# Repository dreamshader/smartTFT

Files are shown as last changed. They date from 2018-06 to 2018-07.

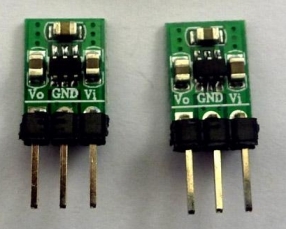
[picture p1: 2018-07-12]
doc/img/2p-mini-2-in-1-dc-dc-step-down-step-up-converter.jpg

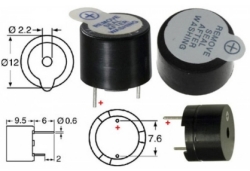
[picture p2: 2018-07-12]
doc/img/piezo-buzzer-specs-700x700_0.jpg

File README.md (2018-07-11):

---

---

<h1 id="smarttft">smartTFT</h1>
<h2 id="brief-description">Brief description</h2>
<p>There is a lot of small and cheap color TFT displays around and with this project I want to give some of them the possibility to remotely control its content. Control is done by most common function calls of the Arduino GFX Library that are transferred to a µController that executes them.</p>
<h2 id="first-prototype">First Prototype</h2>
<p>First prototype is a 1.8" TFT with a ST7735 controller and additional SD-card slot.<br>
As a µController an Arduino Pro Mini is used.<br>
Communication is done using the UART of the Arduino.<br>
A self-made case will hold the components.<br>
A buzzer is used to realize an alarm-function, a LDR makes ist possible to change brightness of the display depending on ambient light.</p>
<p><em><strong>Be aware … this is a work-in-progress project. Some parts may not or not proper work. Use at your own risc!</strong></em></p>
<h2 id="parts-list-1st-prototype">Parts List 1st Prototype</h2>
<ul>
<li>1 x Arduino Pro Mini 1 x 1.8" TFT with SD-slot</li>
<li>2 x Levelshifter with 4 channels</li>
<li>1 x Stepup/Stepdown Regulator 5 &lt;-&gt; 3V3</li>
<li>1 x LDR</li>
<li>1 x Buzzer</li>
<li>1 x Resistor 10 kOhm</li>
<li>2 x Resistor 4.7 kOhm</li>
<li>1 x Resistor 100 Ohm</li>
<li>2 x Ceramic Capacitor 100 nF</li>
<li>1 x Proto-PCB 16 rows/32 columns (around 42 x 83 mm)</li>
<li>1 x Proto-PCB 16 rows/6 columns (around 42 x 15 mm)</li>
<li>1 x Stereo Jack female 3.5 mm</li>
<li>1 x DC Jack female 3.5 mm x 1.1 mm</li>
<li>1 x 4x1 Pin Header</li>
<li>a bunch of colored wires 0.14 mm</li>
</ul>
<h2 id="wiring-via-levelshifter">Wiring via Levelshifter</h2>

<table>
<thead>
<tr>
<th>Arduino</th>
<th>Levelshifter</th>
<th>Levelshifter</th>
<th>1.8" TFT</th>
</tr>
</thead>
<tbody>
<tr>
<td>Pin #10</td>
<td>HV*</td>
<td>LV**</td>
<td>TFT_CS</td>
</tr>
<tr>
<td>Pin #9</td>
<td>HV</td>
<td>LV</td>
<td>TFT_RST</td>
</tr>
<tr>
<td>Pin #8</td>
<td>HV</td>
<td>LV</td>
<td>TFT_DC</td>
</tr>
<tr>
<td>Pin #13</td>
<td>HV</td>
<td>LV</td>
<td>TFT_SCL</td>
</tr>
<tr>
<td>Pin #11</td>
<td>HV</td>
<td>LV</td>
<td>TFT_SDA</td>
</tr>
<tr>
<td>Pin #7</td>
<td>HV</td>
<td>LV</td>
<td>SD_CS</td>
</tr>
<tr>
<td>Pin #12</td>
<td>HV</td>
<td>LV</td>
<td>SD_MISO</td>
</tr>
<tr>
<td>Pin #11</td>
<td>HV</td>
<td>LV</td>
<td>SD_MOSI</td>
</tr>
<tr>
<td>Pin #13</td>
<td>HV</td>
<td>LV</td>
<td>SD_SCL</td>
</tr>
</tbody>
</table><p>*HV means High Voltage Side<br>
**LV means Low Voltage Side</p>
<hr>
<p>Because Vcc of the TFT is 5V <strong>be aware</strong> that <strong>Jumper J1</strong> on the back side of TFT is <strong>open!</strong> Otherwise the display is damaged.</p>
<h2 id="direct-wiring">Direct Wiring</h2>

<table>
<thead>
<tr>
<th>Arduino</th>
<th>Target 1</th>
<th>Target 2</th>
<th>is for</th>
</tr>
</thead>
<tbody>
<tr>
<td>Pin #5</td>
<td>100 Ohm</td>
<td>buzzer</td>
<td>limit current</td>
</tr>
<tr>
<td>Pin #6</td>
<td>TFT LED+</td>
<td>–</td>
<td>dim backlight</td>
</tr>
<tr>
<td>Pin A0</td>
<td>LDR</td>
<td>–</td>
<td>light sense</td>
</tr>
<tr>
<td>Pin A0</td>
<td>10 kOhm</td>
<td>GND</td>
<td>pulldown</td>
</tr>
</tbody>
</table><h2 id="realized-gfx-functions">Realized GFX-functions</h2>
<ul>
<li>drawLine()</li>
<li>drawFastHLine()</li>
<li>drawFastVLine()</li>
<li>drawRect()</li>
<li>fillRect()</li>
<li>drawCircle()</li>
<li>fillCircle()</li>
<li>drawTriangle()</li>
<li>fillTriangle()</li>
<li>drawRoundRect()</li>
<li>fillRoundRect()</li>
<li>setRotation()</li>
<li>setTextWrap()</li>
<li>fillScreen()</li>
<li>setTextColor()</li>
<li>fillScreen()</li>
<li>invertDisplay()</li>
<li>drawCircleHelper()</li>
<li>fillCircleHelper()</li>
<li>drawBitmap()</li>
<li>drawChar()</li>
<li>setCursor()</li>
<li>setTextSize()</li>
<li>height()</li>
<li>width()</li>
<li>write()</li>
<li>drawPixel()</li>
<li>print()</li>
<li>println()</li>
</ul>
<p>and. last but not least,</p>
<ul>
<li>setbrightness()</li>
</ul>
<p>for dimming backlight of the TFT Display.</p>

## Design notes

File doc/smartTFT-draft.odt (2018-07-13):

smartTFT

Control TFT and TFT Touch Displays remotely

# Brief description

There is a lot of small and cheap color TFT displays around and with this project I want to give some of them the possibility to remotely control its content. Control is done by most common function calls of the Arduino GFX Library that are transferred to a µController that executes them.

µControllers that may be used are several typed of Arduino (e.g. Pro Mini) and the ESP8266 Series as well as the ESP32xx Series SoCs.

The displays that are suitable to use are the several 0.96“, 1.2“, 1.8“, 2.2“ … TFT displays and TFT displays with touch interface.

For more information about µControllers and displays see appendix A.

# Proof of concept and 1st prototype

First prototype and proof of concept is done with a ST7735 based 1.8" TFT with an additional SD-card slot.

As a µController an Arduino Pro Mini is used.

Communication is done using the UART of the Arduino.

A self-made case will hold the components.

A buzzer is used to realize an alarm-function, a LDR makes ist possible to change backlight brightness of the display depending on ambient light.

## Prototype Electronic Components

### Arduino Pro Mini

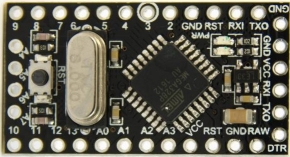
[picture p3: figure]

There are several different models of the Arduino Pro Mini available. There is no need for choosing a specific model but it is recommended not to use a 3V3 type.

### 1.8“ TFT Display

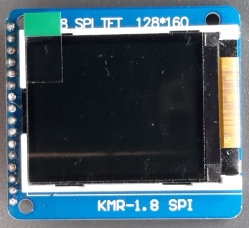
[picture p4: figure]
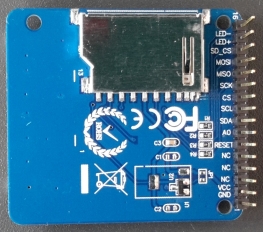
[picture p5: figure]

This documentation requires the use of a 16 pin 1.8“ TFT with card slot, based on a ST7735 controller. Keep in mind not to close jumper J1 to avoid damage of the display.

### 4 channel logic level shifter

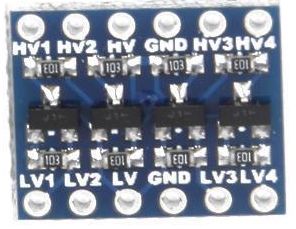
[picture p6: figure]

There is no special to annotate to this items. You may use a 8 channel level shifter instead of two pieces with 4 channels, but then you have to change the wiring to match this new condition.

### Stepup/Stepdown regulator


These are special items that will work with an input voltage from 1.8V up to 5V and will deliver a max. current of 100 mA @3.3V.

3.3V are necessary for the logical signals even if the display is powered by 5V.

### Light Dependend Resistor (LDR)

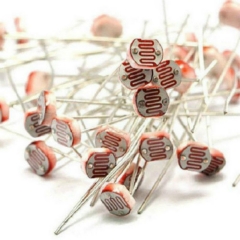
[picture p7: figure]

These cheap items will match our needs. You may get a bunch of them for only some cent. There is no reason to use other ones.

### Piezo Buzzer


This item is a standard component, too. You may use any type of buzzer working at 5V but hold in mind that the case construction only supports one with these technical data (e.g. diameter, height, ...).

### Resistors

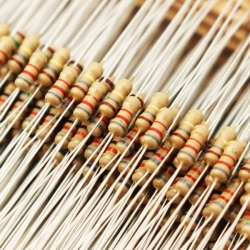
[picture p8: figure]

We need simple carbon resistors with ¼ W, one with 100 Ohm, two with 4.7 kOhm and one with 10 kOhm. See Prototype Parts List below.

### Ceramic Capacitors

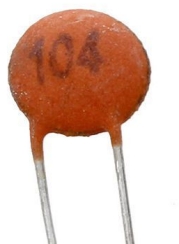
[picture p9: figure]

We need two pieces as decoupling capacitor, one for the TFT and one for the Arduino. For details have a look to the “Prototype Parts List”.

### Stereo Jack 3.5 mm

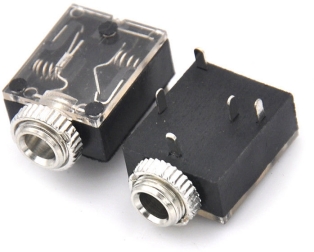
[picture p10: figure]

This is used to connect the UART pins. See sections “Preparing the Prototype PCBs” and “Wiring the Prototype” for more details.

### DC Jack

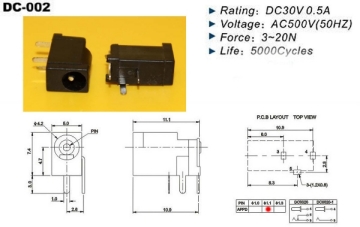
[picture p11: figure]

Connector for power supply (5V). See sections “Preparing the Prototype PCBs” and “Wiring the Prototype” for more details.

### Pin Header 90 degree

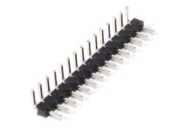
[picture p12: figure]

This header is used to connect the smartTFT to an I2C-Bus. Only three pins are used for SDA, SCL and GND. See sections “Preparing the Prototype PCBs” and “Wiring the Prototype” for more details.

### Prototype PCB

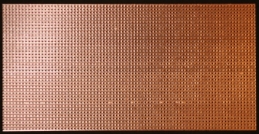
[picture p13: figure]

We need two small pieces of it. See section “Preparing the Prototype PCBs” for dimensions.

### Crimp Headers

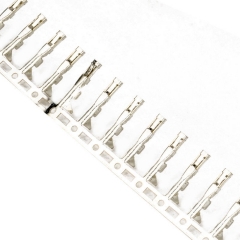
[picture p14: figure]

For the Prototype we’ll wire some connections with these for easily change them.

### Some Colored Wires

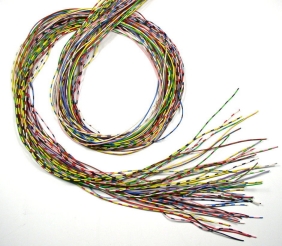
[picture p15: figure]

To make life easier onnections are made by colored wires.

### Prototype Parts List

- 1 x Arduino Pro Mini
- 1 x 1.8" TFT with SD-slot
- 2 x Levelshifter with 4 channels
- 1 x Stepup/Stepdown Regulator 5 <-> 3V3
- 1 x LDR
- 1 x Buzzer
- 1 x Resistor 10 kOhm
- 2 x Resistor 4.7 kOhm
- 1 x Resistor 100 Ohm
- 2 x Ceramic Capacitor 100 nF
- 1 x Stereo Jack female 3.5 mm
- 1 x DC Jack female 3.5 mm x 1.1 mm
- 1 x 4x1 Pin Header 90 degree
- 1 x Proto-PCB 16 rows/32 columns (around 42 x 83 mm)
- 1 x Proto-PCB 16 rows/6 columns (around 42 x 15 mm)
- some crimp headers
- a bunch of colored wires 0.14 mm

## Preparing the Prototype PCBs

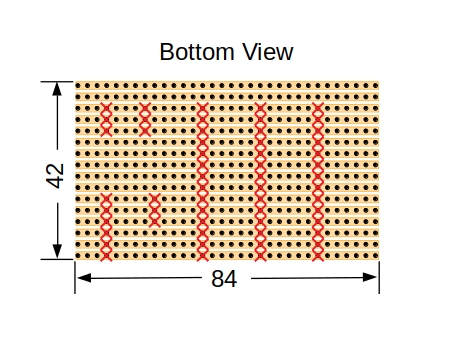
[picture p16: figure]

Cut off a piece from the strip board matching above size. Cut all connections where a red cross appears in the above drawing using a drill or a cutter knife. This will be used as the mainboard.

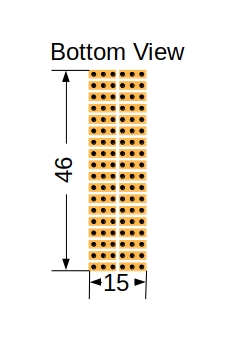
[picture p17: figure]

Cut a smaller piece from the strip board with sizes mentioned above for the connector board.

## Wiring the Prototype

### Textual Description

Arduino | Via | To | Target
Pin #10 | HV* | LV** | TFT_CS
Pin #9 | HV | LV | TFT_RST
Pin #8 | HV | LV | TFT_DC
Pin #13 | HV | LV | TFT_SCL
Pin #11 | HV | LV | TFT_SDA
Pin #7 | HV | LV | SD_CS
Pin #12 | HV | LV | SD_MISO
Pin #11 | HV | LV | SD_MOSI
Pin #13 | HV | LV | SD_SCL
Pin #5 | 100 Ohm | Buzzer +
Pin #6 | -- | TFT LED+
Pin A0 | -- | LDR
Pin A0 | 10 kOhm | GND

*HV means Levelshifter High Voltage Side

**LV means Levelshifter Low Voltage Side

### Visualization of wiring

### Schematic

## Complete the Prototype

## Software on Arduino

## Linux Testprogram

## Conclusion

Realized GFX-functions

- drawLine()

- drawFastHLine()

- drawFastVLine()

- drawRect()

- fillRect()

- drawCircle()

- fillCircle()

- drawTriangle()

- fillTriangle()

- drawRoundRect()

- fillRoundRect()

- setRotation()

- setTextWrap()

- fillScreen()

- setTextColor()

- fillScreen()

- invertDisplay()

- drawCircleHelper()

- fillCircleHelper()

- drawBitmap()

- drawChar()

- setCursor()

- setTextSize()

- height()

- width()

- write()

- drawPixel()

- print()

- println()

and. last but not least,

- setbrightness()

for dimming backlight of the TFT Display.

smartTFT draft

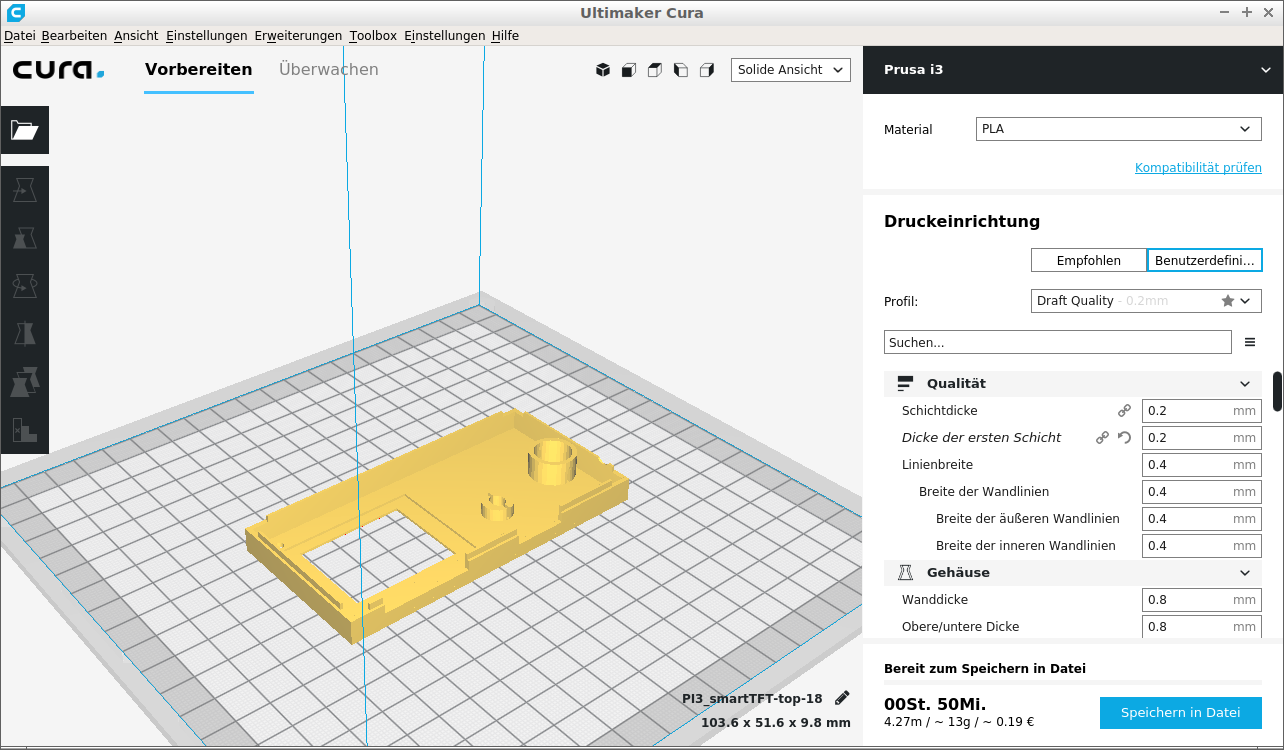
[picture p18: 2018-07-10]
doc/img/smartTFT-cura-top.png

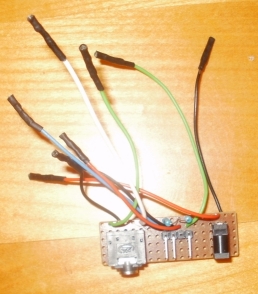
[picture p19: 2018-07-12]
doc/img/smartTFT-connector-small.jpg

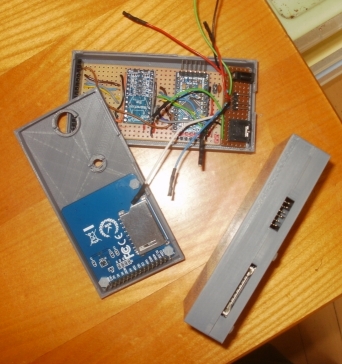
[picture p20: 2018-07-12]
doc/img/smartTFT-proto1-small.jpg

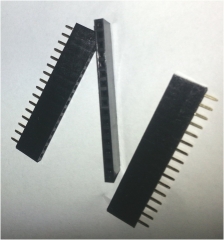
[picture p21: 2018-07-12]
doc/img/pinheader-female.jpg

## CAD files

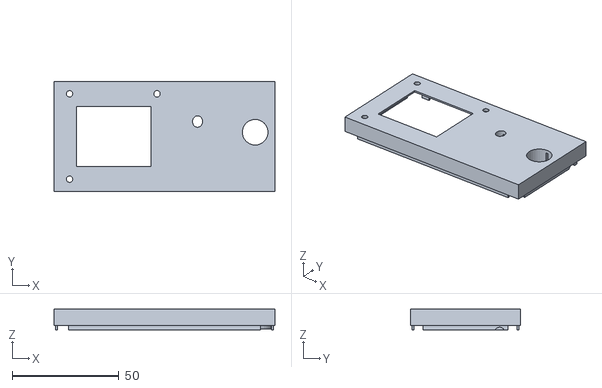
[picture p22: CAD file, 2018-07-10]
blender/exports/smartTFT-top-18.stl
103.6 x 51.6 x 9.80

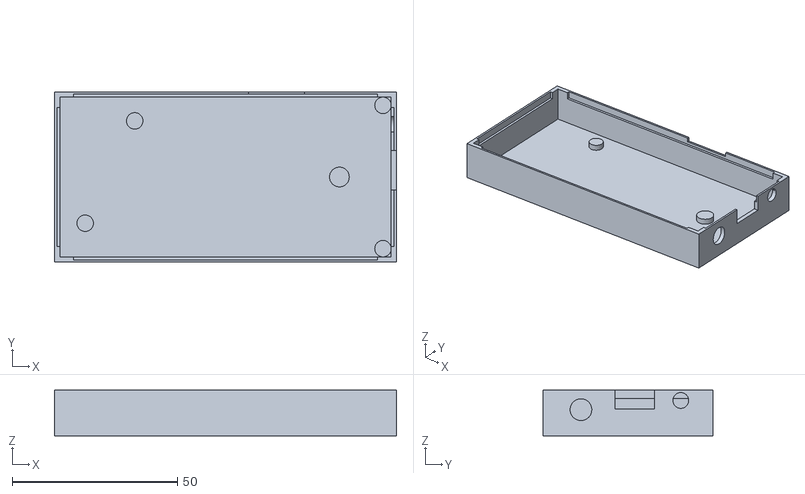
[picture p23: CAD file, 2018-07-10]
blender/exports/smartTFT-bottom-18.stl
103.6 x 51.6 x 13.8

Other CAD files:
blender/ldr.blend
blender/smartTFT-bottom-18.blend
blender/smartTFT-parts-bottom-18.blend
blender/smartTFT-parts-top-18.blend
blender/smartTFT-top-18.blend

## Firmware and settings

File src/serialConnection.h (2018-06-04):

/*
 ***********************************************************************
 *
 *  serialConnection.h - a class for simplifying access to a
 *                       serial line
 *
 *  Copyright (C) 2018 Dreamshader (aka Dirk Schanz)
 *
 *  Licensed under the Apache License, Version 2.0 (the "License");
 *  you may not use this file except in compliance with the License.
 *  You may obtain a copy of the License at
 *  
 *      http://www.apache.org/licenses/LICENSE-2.0
 *  
 *  Unless required by applicable law or agreed to in writing, software
 *  distributed under the License is distributed on an "AS IS" BASIS,
 *  WITHOUT WARRANTIES OR CONDITIONS OF ANY KIND, either express or implied.
 *  See the License for the specific language governing permissions and
 *  limitations under the License.
 *
 ***********************************************************************
 */

#ifndef _SERIAL_CONNECTION_H_
#define _SERIAL_CONNECTION_H_

#include <iostream>
#include <string>
#include <sys/types.h>
#include <stdio.h>
#include <stdlib.h>
#include <unistd.h>
#include <string.h>
#include <stdbool.h>
#include <sys/param.h>
#include <fcntl.h>
#include <termios.h>


#ifdef __cplusplus
extern "C" {
#endif
 
using namespace std;

#define DEFAULT_CONNECTIONTYPE -1
#define DEFAULT_DEVICE           "/dev/ttyUSB0"
#define DEFAULT_BAUD             38400
#define DEFAULT_DATABIT          8
#define DEFAULT_STOPBITS         1
#define DEFAULT_PARITY           'N'
#define DEFAULT_HANDSHAKE        'N'

#define E_OK                       0
#define E_FAIL                    -1

#define E_PARAM_BAUDRATE         -10
#define E_PARAM_DATABIT	         -11
#define E_PARAM_PARITY	         -12
#define E_PARAM_STOPBITS         -13
#define E_PARAM_HANDSHAKE        -14
#define E_PARAM_DEVICE           -15
#define E_PARAM_NULL             -16
#define E_PARAM_NOFD             -17
#define E_PARAM_LENGTH           -18
#define E_NULL_CONNECTION        -19

#define CONNECTION_TYPE_UART      'u'
#define CONNECTION_TYPE_I2C       'i'
#define CONNECTION_TYPE_SPI       's'

#define CONNTYPE_SET            1

#define INATERFACE_SET          2
#define SPEED_SET               4
#define PARITY_SET              8
#define DATABITS_SET           16
#define STOPBITS_SET           32
#define UART_PARAM_COMPLETE    63

#define I2CSDA_SET              2
#define I2CSCL_SET              4
#define I2CADDR_SET             8
#define I2C_PARAM_COMPLETE     15

#define SPIMOSI_SET             2
#define SPIMISO_SET             4
#define SPISCLK_SET             8
#define SPICS_SET              16
#define SPI_PARAM_COMPLETE     31



// #define SEND_BUFFER_SIZE    1024

class serialConnection {

    private:
        int16_t        dev_fd;
        struct termios newtio;
        bool           dataReceived;
        int8_t         connType;
        uint32_t       connFlags;

        char           *device;
        uint32_t       baud;
        int16_t        databits;
        int8_t         parity;
        int16_t        stopbits;
        int8_t         handshake;

//     uint8_t _sendBuffer[SEND_BUFFER_SIZE];

    public:
        int            errorNum;

        serialConnection( char *devname = (char*) DEFAULT_DEVICE, 
                          uint32_t baud = DEFAULT_BAUD, 
                          int16_t databits = DEFAULT_DATABIT, 
                          int8_t parity = DEFAULT_PARITY, 
                          int16_t stopbits = DEFAULT_STOPBITS, 
                          int8_t handshake = DEFAULT_HANDSHAKE )
        {

            if( isValidDevice( devname ) )
            {
                this->device = strdup(devname);
                if( isValidBaud( baud ) )
                {
                    this->baud = baud;
                    if( isValidDatabits( databits ) )
                    {
                        this->databits = databits;
                        if( isValidParity( parity ) )
                        {
                            this->parity = parity;
                            if( isValidStopbits( stopbits ) )
                            {
                                this->stopbits = stopbits;
                                if( isValidHandshake( handshake ) )
                                {
                                    this->handshake = handshake;
                                }
                            }
                        }
                    }
                }
            }
        }


        bool isValidBaud( uint32_t baud );
        bool isValidDatabits( int16_t databits );
        bool isValidParity( int8_t parity );
        bool isValidStopbits( int16_t stopbits );
        bool isValidHandshake( int8_t handshake );
        bool isValidDevice( char* pDeviceName );

        int set_termios( void );

        int setup( char *devname, uint32_t baud, int16_t databits,
                   int8_t parity, int16_t stopbits, int8_t handshake );

        int ser_open( char *devname, uint32_t baud, short databits, 
                  int8_t parity, int16_t stopbits, int8_t handshake );

        int ser_open( void );

        int ser_close( void );
        int ser_read( char* pBuffer, int bufLen );
        int ser_write( char* pBuffer, int wrLen );


};

#ifdef __cplusplus
}
#endif


#endif // _SERIAL_CONNECTION_H_

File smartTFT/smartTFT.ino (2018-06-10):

/***************************************************
 smartTFT ...

    Copyright (C) 2018 Dreamshader (aka Dirk Schanz)

    Licensed under the Apache License, Version 2.0 (the "License");
    you may not use this file except in compliance with the License.
    You may obtain a copy of the License at

        http://www.apache.org/licenses/LICENSE-2.0

    Unless required by applicable law or agreed to in writing, software
    distributed under the License is distributed on an "AS IS" BASIS,
    WITHOUT WARRANTIES OR CONDITIONS OF ANY KIND, either express or implied.
    See the License for the specific language governing permissions and
    limitations under the License.

Der Sketch verwendet 25900 Bytes (84%) des Programmspeicherplatzes. Das Maximum sind 30720 Bytes.
Globale Variablen verwenden 1289 Bytes (62%) des dynamischen Speichers, 759 Bytes für lokale Variablen verbleiben. Das Maximum sind 2048 Bytes.



 ****************************************************/

#include <Adafruit_GFX.h>    // Core graphics library
#include <Adafruit_ST7735.h> // Hardware-specific library
#include <SPI.h>
#include <Wire.h>
#include <SD.h>


//
#define TFT_BACKLIGHT        6
#define LDR_INPUT           A0
//
#define TFT_CS              10
#define TFT_RST              9
#define TFT_DC               8
#define TFT_SCLK            13
#define TFT_MOSI            11
#define SD_CS                7
#define SD_MISO             12
#define SD_MOSI       TFT_MOSI
#define SD_SCLK       TFT_SCLK
//
#define SERIAL_BAUD      38400
#define I2C_ADDRESS         12
#define SD_CHECK_INTVAL  10000
#define LDR_CHECK_INTVAL  2000

//


#define BACKLIGHT_FULL     255
#define BACKLIGHT_OFF        0
#define DEFAULT_BACKLIGHT    BACKLIGHT_FULL

#define DEFAULT_FG_COLOR     ST7735_BLACK
#define DEFAULT_BG_COLOR     ST7735_WHITE

//
// some globals needed 
//
Adafruit_ST7735 tft = Adafruit_ST7735(TFT_CS,  TFT_DC, TFT_RST);
bool cardPresent = false;
String inputString = "";         // a String to hold incoming data
boolean stringComplete = false;  // whether the string is complete
uint16_t tftBackgroundColor;
uint16_t tftForegroundColor;
//
// SD related
//
Sd2Card card;
SdVolume volume;
SdFile root;
//
//

// function that executes whenever data is requested by master
// this function is registered as an event, see setup()
void requestEvent() 
{
    Wire.write("hello "); // respond with message of 6 bytes
                          // as expected by master
}

// function that executes whenever data is received from master
// this function is registered as an event, see setup()
void receiveEvent(int howMany) 
{
    while (1 < Wire.available()) 
    { // loop through all but the last
        char c = Wire.read(); // receive byte as a character
        Serial.print(c);         // print the character
    }

    int x = Wire.read();    // receive byte as an integer
    Serial.println(x);         // print the integer
}

//
// ------------------------------
//
/*
  SerialEvent occurs whenever a new data comes in the hardware serial RX. This
  routine is run between each time loop() runs, so using delay inside loop can
  delay response. Multiple bytes of data may be available.
*/
#ifdef NEVERDEF
void serialEvent() {
  while (Serial.available()) {
    // get the new byte:
    char inChar = (char)Serial.read();
    // add it to the inputString:
//    inputString += inChar;
    // if the incoming character is a newline, set a flag so the main loop can
    // do something about it:
    if (inChar == '\n') 
    {
        stringComplete = true;
    }
    else
    {
      inputString += inChar;
    }
  }
}
#endif

#define CMD_INVAL             -1
#define CMD_NONE               0
#define CMD_SET_BG             1	
#define CMD_SET_FG             2
#define CMD_BRIGHTNESS         3
#define CMD_PRINTTEXT          4
#define CMD_TEXTWRAP           5
#define CMD_SETROTATION        6
#define CMD_CLEAR              7
#define CMD_DRAWTEXT           8
#define CMD_DRAWLINE           9
#define CMD_FAST_H_LINE       10
#define CMD_FAST_V_LINE       11
#define CMD_DRAWRECT          12
#define CMD_FILLRECT          13
#define CMD_DRAWCIRCLE        14
#define CMD_FILLCIRCLE        15
#define CMD_DRAWTRIANGLE      16
#define CMD_FILLTRIANGLE      17
#define CMD_DRAWROUNDRECT     18
#define CMD_FILLROUNDRECT     19
#define CMD_FILLSCREEN        20
#define CMD_INVERTDISPLAY     21
#define CMD_DRAWCIRCLEHELPER  22
#define CMD_FILLCIRCLEHELPER  23
#define CMD_DRAWBITMAP        24
#define CMD_DRAWCHAR          25
#define CMD_SETCURSOR         26
#define CMD_SETTEXTSIZE       27

#define CMD_TFT_HEIGHT        28
#define CMD_TFT_WIDTH         29
#define CMD_DRAWPIXEL         30
#define CMD_TFT_WRITE         31
#define CMD_TFT_PRINT         32
#define CMD_TFT_PRINTLN       33
#define CMD_SETTEXTCOLOR      34



#define MAX_ARGS            7

// Color definitions
//#define  ST7735_BLACK   0x0000
//#define ST7735_BLUE    0x001F
//#define ST7735_RED     0xF800
//#define ST7735_GREEN   0x07E0
//#define ST7735_CYAN    0x07FF
//#define ST7735_MAGENTA 0xF81F
//#define ST7735_YELLOW  0xFFE0
//#define ST7735_WHITE   0xFFFF

void tftPrintText( int xPos, int yPos, uint16_t color, int textSize, bool wrap, char* pText )
{
  tft.setTextWrap(wrap);
  tft.setCursor(xPos, yPos);
  tft.setTextColor(color);
  tft.setTextSize(textSize);
  if( pText != NULL )
  {
  tft.print(pText);
  }
  else
  {
  tft.print("NULL!!");
  }
}

void tftDrawText( int xPos, int yPos, int color, int textSize, char* pText )
{
    tftPrintText( xPos, yPos, color, textSize, true, pText );
}

void tftDrawLine(int startX, int startY, int endX, int endY, uint16_t color)
{
    tft.drawLine(startX, startY, endX, endY, color);
}

void tftDrawFastHLine(int xPos, int yPos, int len, uint16_t color)
{
    tft.drawFastHLine(xPos, yPos, len, color);
}

void tftDrawFastVLine(int xPos, int yPos, int len, uint16_t color)
{
    tft.drawFastVLine(xPos, yPos, len, color);
}

void tftDrawRect(int startX, int startY, int width, int height, uint16_t color)
{
    tft.drawRect(startX, startY, width, height, color);
}

void tftFillRect(int startX, int startY, int width, int height, uint16_t color)
{
    tft.fillRect(startX, startY, width, height, color);
}

void tftDrawCircle(int xPos, int yPos, int radius, uint16_t color)
{
    tft.drawCircle(xPos, yPos, radius, color);
}

void tftFillCircle(int xPos, int yPos, int radius, uint16_t color)
{
    tft.fillCircle(xPos, yPos, radius, color);
}

void tftDrawTriangle(int topX, int topY, int leftBottomX, int leftBottomY, 
                      int rightBottomX, int rightBottomY, uint16_t color)
{
    tft.drawTriangle(topX, topY, leftBottomX, leftBottomY, 
                     rightBottomX, rightBottomY, color);
}

void tftFillTriangle(int topX, int topY, int leftBottomX, int leftBottomY, 
                      int rightBottomX, int rightBottomY, uint16_t color)
{
    tft.fillTriangle(topX, topY, leftBottomX, leftBottomY, 
                     rightBottomX, rightBottomY, color);
}

void tftDrawRoundRect(int startX, int startY, int width, int height, int radius, uint16_t color)
{
    tft.drawRoundRect(startX, startY, width, height, radius, color);
}

void tftFillRoundRect(int startX, int startY, int width, int height, int radius, uint16_t color)
{
    tft.fillRoundRect(startX, startY, width, height, radius, color);
}

void tftSetRotation( int rotation )
{
    tft.setRotation( rotation );
}


void tftSetTextWrap( bool wrap )
{
    tft.setTextWrap(wrap);
}

void tftClear( void )
{
    tft.fillScreen(tftBackgroundColor);
}

void tftSetBackground( uint16_t color )
{
    tftBackgroundColor = color;
}


void tftSetForeground( uint16_t color )
{
    tftForegroundColor = color;
}


void SetTextColor1Arg(uint16_t fgColor)
{
    tft.setTextColor(fgColor);
}

void SetTextColor2Args(uint16_t fgColor, uint16_t bgColor)
{
    tft.setTextColor(fgColor, bgColor);

}


void tftSetBrightness( int value )
{
    analogWrite(TFT_BACKLIGHT, value);
}


void tftFillScreen( uint16_t color )
{
    tft.fillScreen( color );
}

void tftInvertDisplay( boolean invert )
{
    tft.invertDisplay( invert );
}

void tftDrawCircleHelper( int16_t xPos, int16_t yPos, int16_t radius, int8_t cornername, uint16_t color )
{
    tft.drawCircleHelper( xPos, yPos, radius, cornername, color );
}

void tftFillCircleHelper( int16_t xPos, int16_t yPos, int16_t radius, int8_t cornername, int16_t delta, uint16_t color )
{
    tft.fillCircleHelper( xPos, yPos, radius, cornername, delta, color );
}

void tftDrawBitmap( int16_t xPos, int16_t yPos, const uint8_t *bitmap, int16_t width, int16_t height, uint16_t color )
{
    tft.drawBitmap( xPos, yPos, bitmap, width, height, color );
}

void tftDrawChar( int16_t xPos, int16_t yPos, unsigned char character, uint16_t color, uint16_t background, uint8_t size )
{
    tft.drawChar( xPos, yPos, character, color, background, size );
}

void tftSetCursor( int16_t xPos, int16_t yPos )
{
    tft.setCursor( xPos, yPos );
}

void tftSetTextSize( uint8_t size )
{
    tft.setTextSize( size );
}

int tftHeight( void )
{
    return( tft.height() );
}

int tftWidth( void )
{
    return( tft.width() );
}

// virtual void drawPixel(int16_t x, int16_t y, uint16_t color) = 0;
size_t tftWrite( uint8_t char2Write )
{
    return( tft.write( char2Write ) );
}

  // This MUST be defined by the subclass:
int tftDrawPixel(int xPos, int yPos, uint16_t color)
{
    tft.drawPixel( xPos, yPos, color );
    return(0);
}


//    size_t tft_print(string data);
//    size_t tft_print(const char data[]);
//    size_t tft_print(char data);
//    size_t tft_print(unsigned char data, int fmt = DEC);
//    size_t tft_print(int data, int fmt = DEC);
//    size_t tft_print(unsigned int data, int fmt = DEC);
//    size_t tft_print(long data, int fmt = DEC);
//    size_t tft_print(unsigned long data, int fmt = DEC);
//    size_t tft_print(double data, int fmt = 2);
//    size_t tft_println(void);
int tftPrint_Text( int printCmd, char *pText )
{
    int retVal = 0;
    
    switch( printCmd )
    {
        case CMD_TFT_PRINT:
            tft.print( pText );
            break;
        case CMD_TFT_PRINTLN:
            tft.println( pText );
            break;
    }

    return( retVal );
}

int tftPrint_Long( int printCmd, long argLong )
{
    int retVal = 0;
    
    switch( printCmd )
    {
        case CMD_TFT_PRINT:
            tft.print( argLong );
            break;
        case CMD_TFT_PRINTLN:
            tft.println( argLong );
            break;
    }

    return( retVal );
}

int tftPrint_LongFmt( int printCmd, long argLong, int format )
{
    int retVal = 0;
    
    switch( printCmd )
    {
        case CMD_TFT_PRINT:
            tft.print( argLong, format );
            break;
        case CMD_TFT_PRINTLN:
            tft.println( argLong, format );
            break;
    }

    return( retVal );
}

int tftPrint_Double( int printCmd, double argDouble )
{
    int retVal = 0;
    
    switch( printCmd )
    {
        case CMD_TFT_PRINT:
            tft.print( argDouble );
            break;
        case CMD_TFT_PRINTLN:
            tft.println( argDouble );
            break;
    }

    return( retVal );
}

int tftPrint_DoubleFmt( int printCmd, double argDouble, int format )
{
    int retVal = 0;
    
    switch( printCmd )
    {
        case CMD_TFT_PRINT:
            tft.print( argDouble, format );
            break;
        case CMD_TFT_PRINTLN:
            tft.println( argDouble, format );
            break;
    }

    return( retVal );
}


//
int getInteger( char* pCommand )
{
    int retVal = CMD_INVAL;

    if( pCommand != NULL )
    {
        int i;
        for(i = 0; pCommand[i] != '\0' && !isDigit(pCommand[i]) ; i++ )
            ;

        if( isDigit(pCommand[i]) )
        {
            retVal = atoi(&pCommand[i]);
        }
    }

    return( retVal );
}


uint8_t getUint8( char* pCommand )
{
    uint8_t retVal = CMD_INVAL;

    if( pCommand != NULL )
    {
        int i;
        for(i = 0; pCommand[i] != '\0' && !isDigit(pCommand[i]) ; i++ )
            ;

        if( isDigit(pCommand[i]) )
        {
            retVal = (uint8_t) atoi(&pCommand[i]);
        }
    }

    return( retVal );
}

unsigned char getUChar( char* pCommand )
{
    return( (unsigned char) getUint8( pCommand ) );
}

//

long getLong( char* pCommand )
{
    long retVal = CMD_INVAL;

    if( pCommand != NULL )
    {
        int i;
        for(i = 0; pCommand[i] != '\0' && !isDigit(pCommand[i]) ; i++ )
            ;

        if( isDigit(pCommand[i]) )
        {
            retVal = atol(&pCommand[i]);
        }
    }

    return( retVal );
}


double getDouble( char* pCommand )
{
    double retVal = CMD_INVAL;

    if( pCommand != NULL )
    {
        int i;
        for(i = 0; pCommand[i] != '\0' && !isDigit(pCommand[i]) ; i++ )
            ;

        if( isDigit(pCommand[i]) )
        {
            retVal = atof(&pCommand[i]);
        }
    }

    return( retVal );
}



bool getBoolean( char* pCommand )
{
    bool retVal;

    if( pCommand != NULL )
    {
        int intVal;
        if( (intVal = getInteger( pCommand )) > 0 )
        {
            retVal = true;
        }
        else
        {
            retVal = false;
        }
    }

    return( retVal );
}

//

char *getText( char *pData, int *pLength )
{
    char *retVal = NULL;
    static String resultString = "";

    *pLength = 0;

    if( pData != NULL )
    {
        int txtLength, endText;

        if( pData[0] == '"' )
        {
            pData++;
            for( txtLength = endText = 0; 
                 pData[txtLength] != '\0' && endText == 0; txtLength++ )
            {
                if( pData[txtLength] == '"' )
                {
                    if( txtLength > 0 )
                    {
                        if( pData[txtLength] != '\\' )
                        {
                            endText = 1;
                        }
                    }
                    else
                    {
                        endText = 1;
                    }
                }
                else
                {
                    resultString += pData[txtLength];
                }
            }
            resultString += '\0';
            retVal = resultString.c_str();
        }
        else
        {
            retVal = (char*) "NO TEXT";
        }
    }

    return( retVal );
}

char *getBitmap( char *pData, int *pLength )
{
    char *retVal = NULL;

    *pLength = 0;

    if( pData != NULL )
    {
    }

    return( retVal );
}





int getNextArgPos( char* pCommand )
{
    int retVal = 0;

    if( pCommand != NULL )
    {
        int i;
        for(i = 0; pCommand[i] != '\0' && pCommand[i] != ',' ; i++ )
            ;

        switch( pCommand[i] )
        {
            case ',':
                retVal = i+1;
                break;
            default:
                retVal = -1;
                break;
        }
    }

    return( retVal );

}

//
int commandParser( String &dataRead )
{
    int retVal = 0;
    int argInt;
    int argBrightness;
    int argXPos;
    int argYPos;
    int argStartX;
    int argStartY;
    int argWidth;
    int argHeight;
    int argRadius;
    int argTopX;
    int argTopY;
    int argLeftBottomX;
    int argLeftBottomY;
    int argRightBottomX;
    int argRightBottomY;
    int argLen;
    int argEndX;
    int argEndY;
    uint16_t argColor;
    int argSize;
    bool argBoolean;
    int argRotation;
    uint8_t argCornerName;
    uint16_t argDelta;
    unsigned char argChar;
    uint16_t argBackground;
    char* argBitmap = NULL;
    char* argText = NULL;
    int firstArgPos;
    int currArgPos;
    int currArgNum;
    int nextArgPos;
    int textLength;
    int bitmapSize;
    uint16_t argFgColor, argBgColor;
    int setTextColorNumArguments;
    uint8_t argWrite;
    int printNumArguments;
    long printLongArg;
    double printDoubleArg;
    int printArgFmt;

    char *pData = dataRead.c_str();

#ifdef SERIAL_DEBUG
Serial.print("parsing: ");
Serial.println( dataRead );
#endif // SERIAL_DEBUG

    if( pData[0] == 'f' || pData[0] == 'F' )
    {
        for(firstArgPos = 0; pData[firstArgPos] != '\0' && 
              !isDigit(pData[firstArgPos]) ; firstArgPos++ )
            ;
           
        if( isDigit(pData[firstArgPos]) )
        {
            retVal = atoi(&pData[firstArgPos]);

            for(; pData[firstArgPos] != '\0' && 
                  pData[firstArgPos] != '('; firstArgPos++)
                 ;

            if( pData[firstArgPos] == '(' )
            {
                firstArgPos++;
            }
            else
            {
                firstArgPos = -1;
            }

            if( (currArgPos = firstArgPos) >= 0 )
            {
                nextArgPos = 0;
                textLength = 0;
                currArgNum = 1;
                setTextColorNumArguments = 0;
                printNumArguments = 0;

                do
                {
                    currArgPos += nextArgPos;
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
void loop() 
{
    uint16_t  retVal;
    static char result[6];
    static uint32_t lastCheck;
    static uint32_t lastLDRread;

//    if( millis() >= (lastCheck + SD_CHECK_INTVAL) )
//    {
//        if( !cardPresent )
//        {
//            if (SD.begin(SD_CS)) 
//            {
//                Serial.println("sd card OK!");
//                cardPresent = true;
//            }
//        }
//        lastCheck = millis();
//    }
//
//    if( millis() >= (lastLDRread + LDR_CHECK_INTVAL) )
//    {
//        Serial.println( analogRead(LDR_INPUT) );
//        lastLDRread = millis();
//    }
    
    // print the string when a newline arrives:


  while (Serial.available()) 
  {
    // get the new byte:
    char inChar = (char)Serial.read();
    // add it to the inputString:
//    inputString += inChar;
    // if the incoming character is a newline, set a flag so the main loop can
    // do something about it:
    if (inChar == '\n') 
    {
        retVal = commandParser( inputString );
//        delay(50);

//        Serial.println(inputString);
        Serial.println(retVal);
        inputString = "";

//        stringComplete = true;
    }
    else
    {
      inputString += inChar;
    }
  }


#ifdef NEVERDEF
    
    if (stringComplete) 
    {
        retVal = commandParser( inputString );

#ifdef SERIAL_DEBUG
        Serial.print("executing [");
        Serial.print(inputString);
        Serial.print("], result is");
#endif // SERIAL_DEBUG

        Serial.println(retVal);
        stringComplete = false;
        inputString = "";
    }
#endif NEVERDEF    
}

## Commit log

2018-06-02 initial upload
    [smartTFT.fzz]
2018-06-02 dded hardware folder
    [smartTFT.fzz]
2018-06-06 first prototype works
2018-06-10 missing functions drawoPixel(), print(), println() inserted
    [smartTFT.ino]
2018-07-10 first upload of all stuff
    [ldr.blend, smartTFT-bottom-18.blend, smartTFT-bottom-18.stl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]
2018-07-10 now files should be complete
    [tft-18-sd.sch]
2018-07-11 moved some stuff
    [tft-18-sd.sch]
